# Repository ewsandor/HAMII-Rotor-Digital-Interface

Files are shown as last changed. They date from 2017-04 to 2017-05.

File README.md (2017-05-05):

# HAMII Rotor Digital Interface 
An interface to control a CDE HAM II antenna rotor with a computer based on the Rotor-EZ protocol.

<p>
This project uses an Arduino Nano to control relays to position a CDE HAM II rotor.  The software for the rotor is included in the 'software' folder.
</p>

<p>
A schematic and PCB is included in the folder 'pcb'.  
The PCB depends on Eagle librarys provided by the following repositories:<br>
Arduino-Eagle-Cad-Library   -   https://github.com/cyberlink1/Arduino-Eagle-Cad-Library<br>
Maker-Tools-Eagle-Libraries  -   https://github.com/dvdnhm/Maker-Tools-Eagle-Libraries<br>
  -Error exists in Maker-Tools-Eagle-Libraries, NO and NC are reversed on relay schematic symbol. HAMII Rotor Digital Interface has corrected for this error 
 </p>

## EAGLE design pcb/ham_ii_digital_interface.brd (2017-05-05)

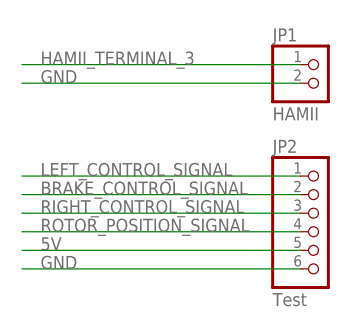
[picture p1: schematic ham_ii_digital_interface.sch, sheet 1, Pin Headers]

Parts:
JP1: HAMII; 1X02
JP2: Test; 1X06

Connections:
5V: JP2.5; also elsewhere on the board
BRAKE_CONTROL_SIGNAL: JP2.2; also elsewhere on the board
GND: JP1.2, JP2.6; also elsewhere on the board
HAMII_TERMINAL_3: JP1.1; also elsewhere on the board
LEFT_CONTROL_SIGNAL: JP2.1; also elsewhere on the board
RIGHT_CONTROL_SIGNAL: JP2.3; also elsewhere on the board
ROTOR_POSITION_SIGNAL: JP2.4; also elsewhere on the board

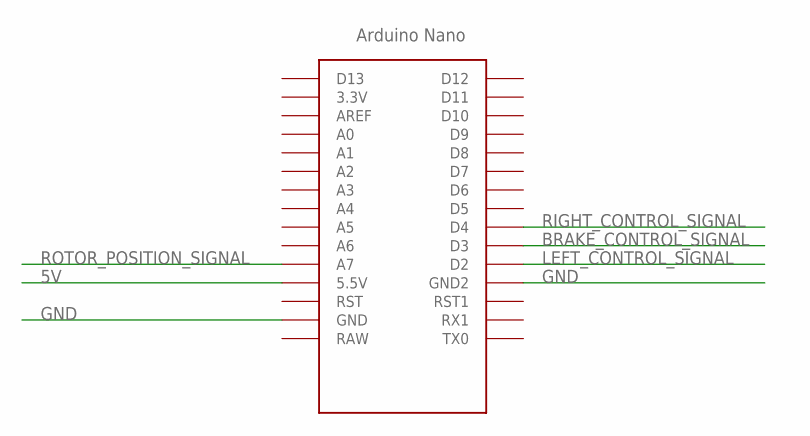
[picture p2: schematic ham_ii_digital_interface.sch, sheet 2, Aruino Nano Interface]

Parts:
U$1: NANO

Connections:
5V: U$1.5V (5.5V); also elsewhere on the board
BRAKE_CONTROL_SIGNAL: U$1.D3; also elsewhere on the board
GND: U$1.GND, U$1.GND1 (GND2); also elsewhere on the board
LEFT_CONTROL_SIGNAL: U$1.D2; also elsewhere on the board
RIGHT_CONTROL_SIGNAL: U$1.D4; also elsewhere on the board
ROTOR_POSITION_SIGNAL: U$1.A7; also elsewhere on the board

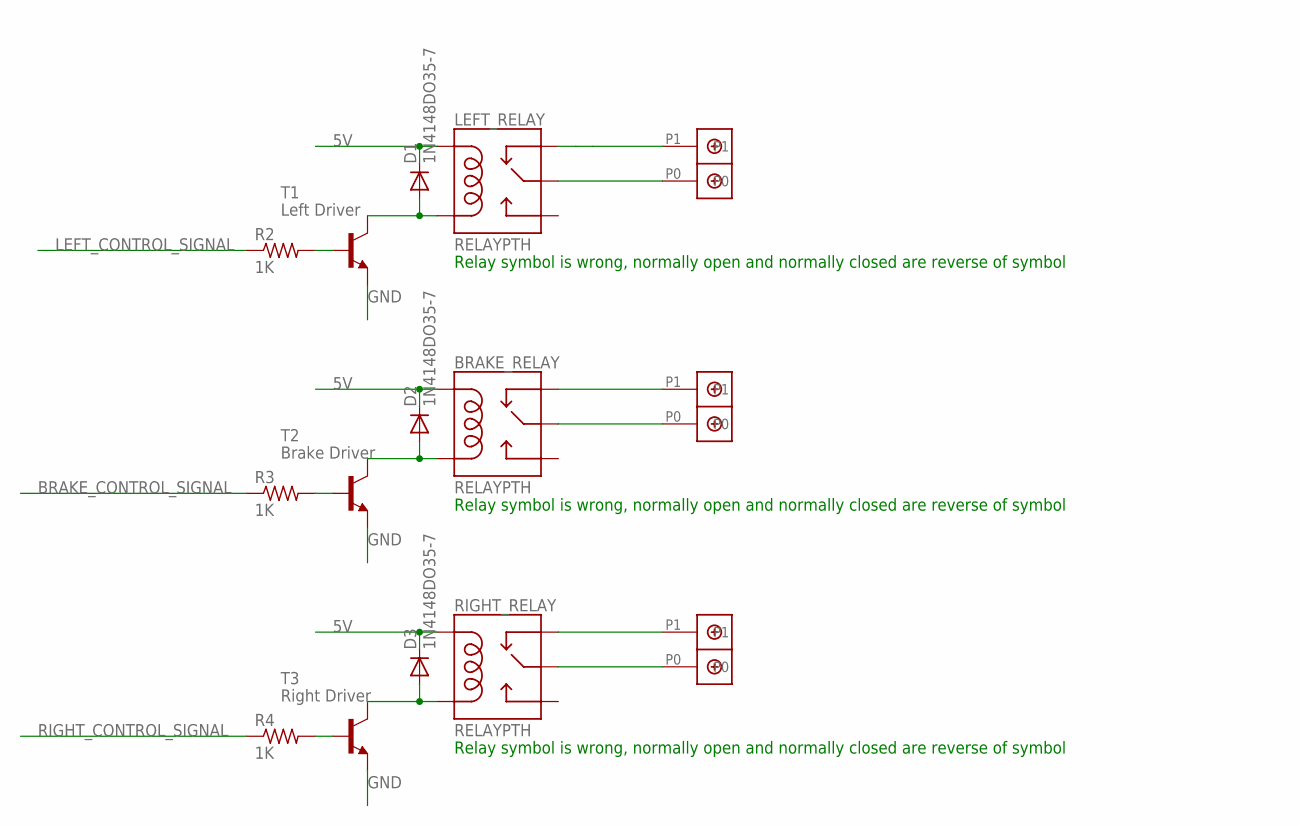
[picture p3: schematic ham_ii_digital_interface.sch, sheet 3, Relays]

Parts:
BRAKE_RELAY: RELAYPTH; SRD-05VDC-SL-C
D1, D2, D3: 1N4148DO35-7; DO35-7
LEFT_RELAY: RELAYPTH; SRD-05VDC-SL-C
R2, R3, R4: 1K; 0207/10
RIGHT_RELAY: RELAYPTH; SRD-05VDC-SL-C
T1: Left Driver; TO92
T2: Brake Driver; TO92
T3: Right Driver; TO92
U$5, U$6, U$7: DBCONN-1X2

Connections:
5V: BRAKE_RELAY.COIL1, D1.C, D2.C, D3.C, LEFT_RELAY.COIL1, RIGHT_RELAY.COIL1; also elsewhere on the board
BRAKE_CONTROL_SIGNAL: R3.1; also elsewhere on the board
GND: T1.1 (E), T2.1 (E), T3.1 (E); also elsewhere on the board
LEFT_CONTROL_SIGNAL: R2.1; also elsewhere on the board
unnamed: LEFT_RELAY.SWCOMMON, U$5.P0
unnamed: LEFT_RELAY.SWCLOSED (SWCLOSE), U$5.P1
unnamed: BRAKE_RELAY.SWCOMMON, U$6.P0
unnamed: BRAKE_RELAY.SWCLOSED (SWCLOSE), U$6.P1
unnamed: RIGHT_RELAY.SWCOMMON, U$7.P0
unnamed: RIGHT_RELAY.SWCLOSED (SWCLOSE), U$7.P1
unnamed: R2.2, T1.2 (B)
unnamed: R3.2, T2.2 (B)
unnamed: R4.2, T3.2 (B)
unnamed: D3.A, RIGHT_RELAY.COIL0, T3.3 (C)
unnamed: BRAKE_RELAY.COIL0, D2.A, T2.3 (C)
unnamed: D1.A, LEFT_RELAY.COIL0, T1.3 (C)
RIGHT_CONTROL_SIGNAL: R4.1; also elsewhere on the board

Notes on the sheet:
Relay symbol is wrong, normally open and normally closed are reverse of symbol

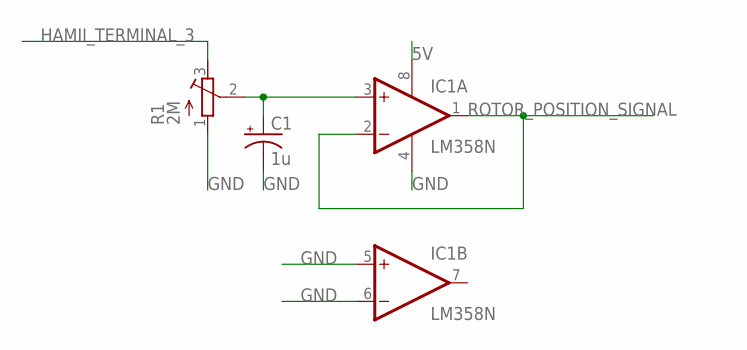
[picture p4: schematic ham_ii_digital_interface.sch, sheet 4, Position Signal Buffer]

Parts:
C1: 1u; E2-5
IC1: LM358N; DIL08
R1: 2M; RTRIM3296W

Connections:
5V: IC1.8 (V+); also elsewhere on the board
GND: C1.-, IC1.4 (V-), IC1.5 (+IN), IC1.6 (-IN), R1.1 (A); also elsewhere on the board
HAMII_TERMINAL_3: R1.3 (E); also elsewhere on the board
unnamed: C1.+, IC1.3 (+IN), R1.2 (S)
ROTOR_POSITION_SIGNAL: IC1.1 (OUT), IC1.2 (-IN); also elsewhere on the board

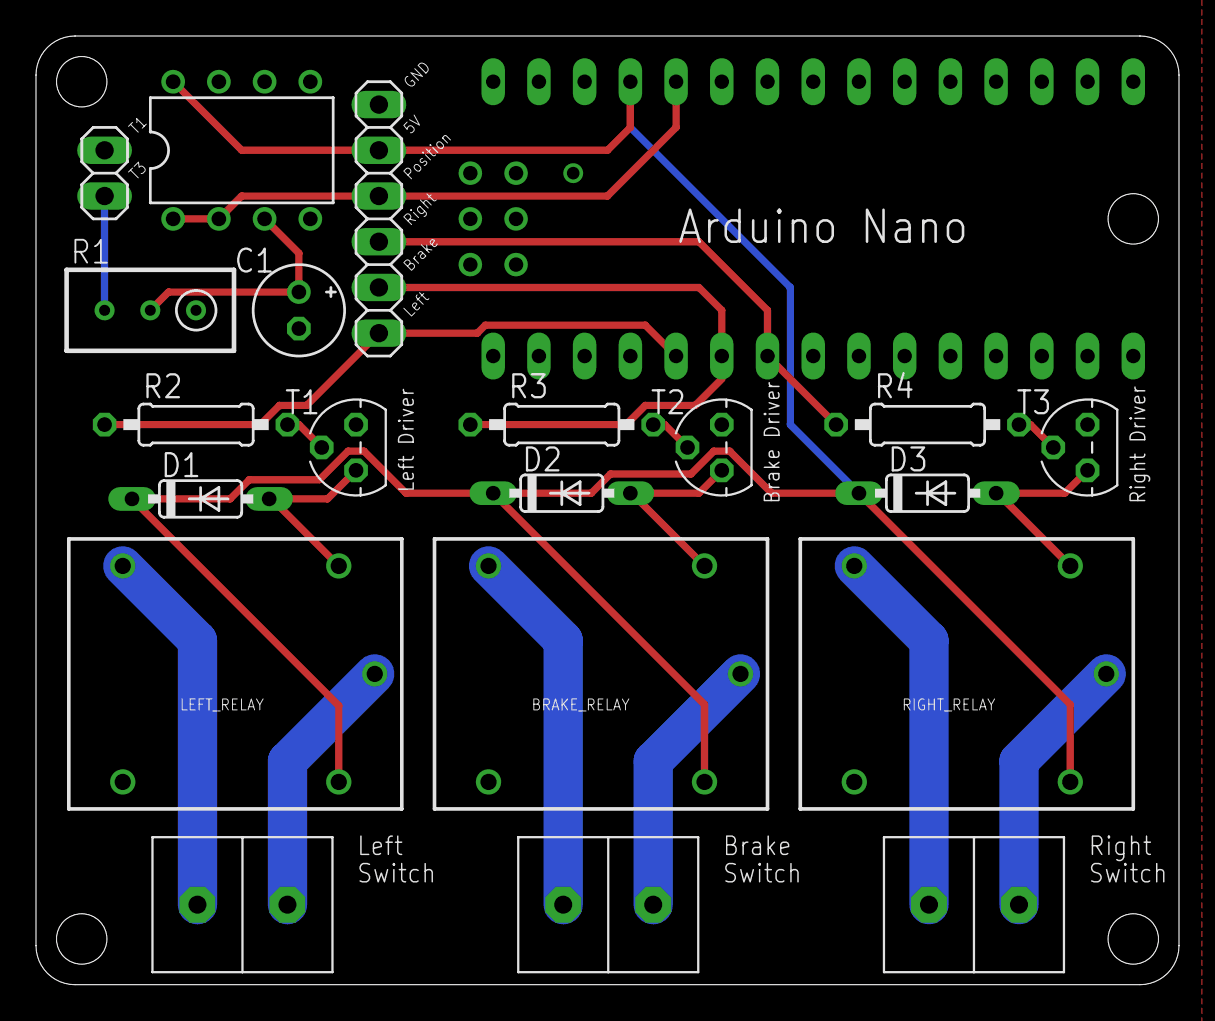
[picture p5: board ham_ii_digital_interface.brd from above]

Board: 2 copper layers, 63.5 x 52.7 mm, 21 parts (0 on the bottom side), 20 nets.

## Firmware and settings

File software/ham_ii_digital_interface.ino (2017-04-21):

const int left =  8;
const int brake = 9;
const int right = 2;
const int potent = 0;
const int TOLERANCE = 1;
const int AMAX = 940;
const int AMIN = 50;
int leftCount;
int rightCount;
int brakeCount;
int   offCount;
int idleCount;
int apCount;
int target;
boolean brakeOff;
boolean turnRight;
boolean turnLeft;
boolean autoRot;
String serialRead;


void setup() {
  for(int i = 0; i<8; i++){
    pinMode(i+2, OUTPUT);
    digitalWrite(i+2, LOW);
  }
    
    
  serialRead="";
  Serial.begin(4800);
  pinMode(left , OUTPUT);      
  pinMode(right, OUTPUT);     
  pinMode(brake, OUTPUT);     
  
  digitalWrite(left, LOW);
  digitalWrite(right, LOW);
  digitalWrite(brake, LOW);
  
  leftCount = 0;
  rightCount = 0;
  brakeCount = 0;
  idleCount = 0;
  target=0;
  brakeOff=false;
  turnLeft=false;
  turnRight=false;
  stopRot();
  apCount = 0;
}

void loop()
{
  //Serial.println(analogRead(potent));
  delay(1);
  idleCount++;
   
    
  if(idleCount > 2000 && brakeCount > 1000 && !turnLeft && !turnRight){
    brakeOff=false;
  }  
  if(brakeOff){
    brakeCount++;    
    digitalWrite(brake, HIGH);
  }
  else{
    digitalWrite(brake, LOW);
    brakeCount=0;
  }
  
  if(turnLeft && turnRight){
    turnLeft = false;
    turnRight = false;
    stopRot();
  }
  
  
  ////////////////////LEFT TURN/////////////////
  if(turnLeft){
    brakeOff = true;

    if(idleCount > 2000 && brakeCount>1000){
      digitalWrite(left, HIGH);
      leftCount++;
    }
    if(leftCount > 500){
      idleCount=0;
      turnLeft = false;
    }
  }
  else
      digitalWrite(left, LOW);
  ////////////////////RIGHT TURN/////////////////
  if(turnRight){
    brakeOff = true;

    if(idleCount > 2000 && brakeCount>1000){
      digitalWrite(right, HIGH);
      rightCount++;
    }
    if(rightCount > 500){
      idleCount=0;
      turnRight = false;
    }
  }
  else{
      digitalWrite(right, LOW);
  }
  ///////////////////Auto Rotate//////////////////
  int head=getHeading();
  if(autoRot){
    if(abs(head-target)<TOLERANCE){
      stopRot();
      turnLeft=false;
      turnRight=false;
    }
    else if(head>target){
      turnLeft=true;
      turnRight=false;
      leftCount=0;
    }
    else if(head<target){
      turnLeft=false;
      turnRight=true;
      rightCount=0;
    }
  }
}

void serialEvent(){
      
  char inChar='e';
  
    //delay(200);
  while(Serial.available()>0){
    inChar = (char)Serial.read();
    
    switch (inChar){
    case 'b':
      autoRot=false;
      brakeCount = 0;
      brakeOff=true;
      break;
    case 'l':
      autoRot=false;
      leftCount=0;
      turnLeft=true;
      break;
    case 'r':
      autoRot=false;
      rightCount=0;
      turnRight=true;
      break;
    case 'c':
      autoRot=true;
      break;
    case 's':
      stopRot();
      break;
    case 'g':
      reportHeading();
      break;
    case 'w':
      Serial.println(analogRead(potent));
      break;
    }
    
    if(inChar == 'A'){
      serialRead="A";
    }
    else if(serialRead.length()==1 && serialRead.compareTo("A") == 0)
    {
      
      if(inChar=='P' || inChar=='M' || inChar=='I'){
        serialRead=serialRead + inChar;
      }
    }
    else if(serialRead.length()==2 && (serialRead.compareTo("AP")==0 || serialRead.compareTo("AM")==0 || serialRead.compareTo("AI")==0) && inChar=='1'){
        serialRead=serialRead + inChar;
    }
    else if(serialRead.length()==3 && serialRead.compareTo("AM1") == 0 && inChar==';'){
        autoRot=true;
        serialRead="";
    }
    else if(serialRead.length()==3 && serialRead.compareTo("AI1") == 0 && (inChar==';' || inChar=='\r')){
      
        reportHeading();
        serialRead="";
    }
    else if(serialRead.length()>=3 && serialRead.length()<6 && inChar >= '0' && inChar <='9'){
        serialRead=serialRead+inChar;
    }
    else if(serialRead.length()==6){
      if(inChar == ';'){
        stopRot();
      }
      else if(inChar == '\r'){
        autoRot=true;
      }
      else{
        serialRead="";
      }
      if(serialRead.length()==6){
        int tmp = serialRead.substring(3).toInt();
        if(tmp > 180)
          tmp=tmp-360;
        target = tmp;
      }
      serialRead="";
    }
    else if(inChar==';'){
        stopRot();
        serialRead="";
    }
    else
        serialRead="";
  }
  
  
  
  
}
int getHeading(){
  int raw = analogRead(potent);
  int tmp = ( (int) 360*( ( (double) raw-AMIN )/( AMAX-AMIN ) ) )-180;
  return tmp;
}
void reportHeading(){
  int loc = (getHeading());
  while(loc<0)
    loc=loc+360;
  String outStr=";";
  outStr=outStr+loc;
  Serial.println(outStr);
}
void stopRot(){
    autoRot = false;
    turnLeft = false;
    turnRight = false;
    brakeCount = 0;
    idleCount=0;
    brakeOff= true;
}

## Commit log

2017-04-21 Initial upload of files into git repository
    [ham_ii_digital_interface.brd, ham_ii_digital_interface.sch]
2017-04-23 Changed value of C1 and changed C1 to an electrolytic capacitor.
    [ham_ii_digital_interface.brd, ham_ii_digital_interface.sch]
2017-04-23 Improved trace routing.
    [ham_ii_digital_interface.brd]
2017-04-23 Minor improvments before ordering first run
    [ham_ii_digital_interface.brd]
2017-05-05 Fixed issue discovered after receiving print of PCB. The NO and NC pins on the SRD-05VDC-SL-C schematic symbol are reveresed resulting in incorrect functionality. Trace must be cut on NC pin and a ju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
    [ham_ii_digital_interface.brd, ham_ii_digital_interface.sch]
